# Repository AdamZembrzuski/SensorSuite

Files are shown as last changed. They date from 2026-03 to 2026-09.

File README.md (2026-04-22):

# AZSensorSuite



> [!WARNING]
> This device has been mostly tested, however, problems may arise. Expect changes and please report any inaccuracies or issues.

## Overview
land_export

AZSensorSuite (AZSS) is an ultra-low-power, data-acquisition hardware platform designed to be user-programmed for a variety of applications. 

The included example firmware detects when people pass through a doorway into a closed space. A machine learning model (run on a host computer) can then predict when the space is empty so that services like heating or lighting can be automatically disabled.

**Interactive Viewer:** View the PCB and schematic entirely in your browser on [KiCanvas](https://kicanvas.org/?repo=https%3A%2F%2Fgithub.com%2FAZT-GH%2FSensorSuite%2Ftree%2Fmain%2Fhardware).

### Hardware Features

* **SoC / Connectivity:** Nordic NRF54L15 (via U-Blox Nora B206 module). Supports BLE 6.0, Matter, Thread, Zigbee, and proprietary 2.4GHz communication.
* **ToF Sensor:** ST Microelectronics VL53L4CD. Used for ULP presence detection ([STSW-IMG034](https://www.st.com/en/embedded-software/stsw-img034.html), as low as 154µW) or standard ranging ([STSW-IMG026](https://www.st.com/en/embedded-software/stsw-img026.html)).
* **Environmental Sensor:** Sensirion SHT30 for ambient temperature and humidity readings.
* **Power:** Powered by a CR2032 coin cell, converted to 2.8V. The entire system is ultra-low power (e.g., ~400µA in the human detection example).

> [!TIP]
> The VL53L4CD and SHT30 are both members of pin-compatible sensor families. They can easily be replaced to meet specific project requirements or to navigate supply chain shortages.

## Example Quickstart Guide

### Requirements
* NRF54L15DK (highly recommended) or another SWD debugger.
* SensorSuite PCB and TC2030-IDC-NL cable.
    * *Alternatively:* NRF54L15DK with sensor breakouts.
* [nRF Connect SDK v3.1.1](https://developer.nordicsemi.com/nRF_Connect_SDK/doc/latest/nrf/index.html) via nRF Connect for VS Code.
* Python 3.7 or higher.

### Build and Flash Process
* If working with the development kit, skip step 5 and in `firmware/prj.conf` set `CONFIG_APP_BOARD_IS_PROD=n`.
1.  Clone the repository to a path that contains **no spaces** (e.g., `/projects/sensor_suite` is good; `/projects/sensor suite/` will cause build errors).
2.  Open the application in nRF Connect and navigate to the `firmware` subfolder.
3.  Create a new build configuration:
    * **Target:** `nrf54l15dk/nrf54l15/cpuapp/ns`
    * **Base configuration:** `prj.conf`
    * **Base devicetree overlay:** `boards/nrf54l15dk_nrf54l15_cpuapp_ns.overlay`
    * Select your desired build optimization.
4.  Click **Generate and Build**.
5.  Connect the TC2030-IDC-NL to the DK. The DK will automatically detect it and change the target to the connected custom PCB.
6.  Press **Flash and Erase**. (You may flash without erase after the first flash)
* If a module is being flashed for the first time, it may have memory protections enabled. Click `Yes` in the pop-up to allow recovery.

error

## Release Notes

v1.0.0 - 17/04/26 - Initial release with all core features implemented

## License

Copyright © 2026 Adam Zembrzuski. 

This project is licensed under the TAPR Open Hardware License ([www.tapr.org/OHL](https://www.tapr.org/OHL)).

A full copy of the license is available in the `license.txt` file in this repository.

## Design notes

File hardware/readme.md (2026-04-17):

## Hardware

This folder contains all hardware design files and documentation.

**Interactive Viewer:** View the PCB and schematic entirely in your browser on [KiCanvas](https://kicanvas.org/?repo=https%3A%2F%2Fgithub.com%2FAZT-GH%2FSensorSuite%2Ftree%2Fmain%2Fhardware).
##
### PCB Fabrication

The PCB is four layers, based on the [OshPark](https://docs.oshpark.com/services/four-layer/) 
four-layer stackup. A different stackup may be used if preferable, as only two GPIO traces 
require controlled impedance.

| Parameter | Value |
|---|---|
| Layers | 4 |
| Board thickness | 1.6mm |
| Surface finish | 2µ" ENIG (preferred) |
| Via drill / pad | 0.3 / 0.4mm |
| Via tenting | Tented minimum, plugged preferred |

### Stencil

Electropolished stencils are preferred over 
laser-cut for cleaner paste release on the LGA pads of the Nora B206.

### Assembly Notes

- The U-Blox Nora B206 and ST VL53L4CD are LGA components and **must be reflow soldered**. 
  Hand soldering is not possible.

### Schematic Notes

- **R1** should be replaced to a suitable value for current measurement instead of 0 ohms.
- Several components are marked DNP. These are intended for development boards only 
  and should be omitted on production boards.

> [!TIP]
> If the SHT3x is not required, C11 and U4 can be DNP'd, and in the example firmware, `CONFIG_APP_SHT_ENABLE` should be set to `n`in `firmware/prj.conf`.

### Test Points

Test point layout is visible below and is consistent with the schematic.

test points

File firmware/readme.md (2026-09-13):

## Firmware

This folder contains all firmware source files and documentation. The latest firmware (release v1.0.0)
has been verified working on PCB V1.12 (all functions).

For build and flash instructions, see the 
[main README](../README.md#example-quickstart-guide).
##

### Implementation Status

| Feature | Status |
|---|---|
| VL53L4CD ToF detection | Complete |
| SHT30 temperature / humidity | Complete |
| BLE service | Complete |
| NVM storage | Complete |
| Dynamic ToF interval | Complete |
| SAADC VCC monitoring | Planned |

### BLE Service

The device exposes a custom BLE service with the following characteristics:

Service UUID : `229a0001-ad33-4a06-9bce-c34201743655`

| Characteristic | UUID | Properties | Encryption | Description |
|---|---|---|---|---|
| Count | `229a0002-ad33-4a06-9bce-c34201743655` | Notify, Read | None | Returns detected object count |
| Temperature | `229a0003-ad33-4a06-9bce-c34201743655` | Notify, Read | None | Returns last good temperature |
| Humidity | `229a0004-ad33-4a06-9bce-c34201743655` | Notify, Read | None | Returns last good humidity |
| Bulk Download | `229a0005-ad33-4a06-9bce-c34201743655` | Notify | Level 2 | Used to download timestamp log |
| Current Timestamp | `229a0006-ad33-4a06-9bce-c34201743655` | Read | None | Returns current timestamp |
| Base Timestamp | `229a0007-ad33-4a06-9bce-c34201743655` | Write, Read | Level 2 | Used to write base timestamp |
| Command | `229a0008-ad33-4a06-9bce-c34201743655` | Write, Read | Level 2 | Used to call one of many commands |

### 'Command' Commands

| Command | Hex | Return | Description |
|---|---|---|---|
| Connection Interval 20ms | `0x00` | none | Sets new connection interval |
| Connection Interval 100ms | `0x01` | none | Sets new connection interval |
| Connection Interval 512ms | `0x02` | none | Sets new connection interval |
| Connection Interval 1024ms | `0x03` | none | Sets new connection interval |
| Download Start | `0x10` | 0 on success | Starts timestamp download notifications |
| Download Stop | `0x11` | 0 on success | Stops timestamp download notifications |
| Storage Clear | `0x13` | 0 on success | Clears NVM, including bonding, configuration, and logs |
| Firmware Version | `0x20` |int (eg `12` for V1.2)| Returns FW Version |
| Active Period 08-16 | `0x30` |  0 on success | Sets the device to only detect <sup>¶</sup> between 08:00 and 16:00 |
| Active Period 08-18 | `0x31` |  0 on success | Sets the device to only detect between 08:00 and 18:00 |
| Active Period 09-21 | `0x32` |  0 on success | Sets the device to only detect between 09:00 and 21:00 |
| Active Period 00-24 | `0x33` | 0 on success | Sets the device to detect irrespective of time (not date) |
| Inactive Weekend | `0x34` | 0 on success | Sets the device to not detect during the weekend |
| Active Weekend | `0x35` | 0 on success | Sets the device to detect during the weekend |

*¶ Detect refers to human/object detection, ambient detection is still carried out*

### Data Collection
The device only collects timestamp logs if it is within the active period, definable via the 0x3- commands. The selected active period is stored in NVM.

Ambient logs are collected regardless of the system state (if the SHT3x is enabled in `prj.conf`).

### Logging

*Logging described in this section is independent of sensor logging*

RTT logging is enableable in `prj.conf`. Connect via the nRF Connect for Desktop 
terminal or a J-Link RTT Viewer.

### Kconfig Options
All Kconfig options can be adjusted in `firmware/prj.conf`. If changes are not being applied, ensure `prj.conf` is included in the build config.

#### System Level
<details>
<summary>For lowest current consumption disable all logging, this will reduce current consumption by roughly 200μA</summary>

```
CONFIG_USE_SEGGER_RTT=n
CONFIG_SERIAL=n

CONFIG_LOG=n
CONFIG_LOG_BACKEND_RTT=n
CONFIG_LOG_BACKEND_UART=n

CONFIG_PRINTK=n
CONFIG_BOOT_BANNER=n

CONFIG_UART_CONSOLE=n
CONFIG_RTT_CONSOLE=n
```

</details>
<details>
<summary>Bluetooth options such as device name and default connection interval are available to be defined statically.</summary>
  
```
CONFIG_BT_DEVICE_NAME="AZSensorSuite-001"
```
</details>

#### Application Level

Application specific Kconfig option descriptions can be viewed in the visual kconfig editor, in the nRF  Connect SDK. Below are some key options.

- `CONFIG_APP_VL53_DETECTION_INTERVAL_MS` - Inter-measurement period for the VL53L4CD ToF sensor in milliseconds. Must be a multiple of ten.

- `CONFIG_APP_CONSEC_DETECT_FILTER` - Require multiple consecutive detections before logging an event. Should be paired with a lowered detection interval.

- `CONFIG_APP_SHT_ENABLE` - Disable functions related to the SHT3x, notably it still *remains powered* even in this mode.

- `CONFIG_APP_LOG_FULL_STRATEGY` - Determines if logs are overwritten when full or if writing stops.

- `CONFIG_APP_BOARD_IS_PROD` - Should be set to `n` if building for the nRF5454L15-DK.

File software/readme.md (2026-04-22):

## Software

This folder contains the host-side Python client for communicating with
AZSensorSuite over BLE.

**ML functionality has not been implemented yet, and will not be implemented in the forseeable future.**

> [!WARNING]
> The software in this folder has been heavily vibecoded. Expect unreliability. (A human rewrite is planned)

*Python 3.7 or higher is required.*

##

### Overview

The intended data flow is:
```
Device (BLE) → azss_client.py → csvs/ → azss_train.py → model → azss_infer.py → prediction
```

The BLE client is currently implemented. Model training and infer scripts 
are in progress.

## azss_client.py
### Setup
```bash
pip install -r requirements.txt
```

> [!NOTE]
> On macOS, Bleak exposes CoreBluetooth UUIDs rather than MAC addresses. 
> When prompted for a Bluetooth address, use the UUID string instead.

### Usage
```bash
python azss_client.py
```

The client runs as an interactive shell. Type `help` for a list of commands 
or `exit` to quit.

### Commands

| Command | Requires Connection | Description |
|---|---|---|
| `scan` | No | Scan for nearby BLE devices |
| `connect` | No | Connect to a device by Bluetooth address |
| `disconnect` | No | Disconnect from the current device |
| `unpair` | No | Unpair the current device |
| `read uuid` | Yes | Read a characteristic by UUID |
| `read count` | Yes | Read detected object count since last initialisation |
| `read temp` | Yes | Read temperature (returns °C, °F, and K) |
| `read humidity` | Yes | Read relative humidity |
| `read time` | Yes | Read the current device timestamp in milliseconds |
| `write` | Yes | Send a raw hex command byte to the Command characteristic |
| `write time` | Yes | Sync device base timestamp to system time |
| `write time custom` | Yes | Write a custom base timestamp in milliseconds |
| `download` | Yes | Download the full timestamp and ambient log |

### Download Output

Data is written to the `csvs/` folder, created automatically if it does not exist.

**`stamps.csv`** — ToF event log

| Column | Description |
|---|---|
| `row` | Row index |
| `seq` | BLE packet sequence number |
| `delta_i32` | Time delta from previous event in seconds |
| `cumulative_i64` | Cumulative elapsed seconds since base timestamp |
| `real_i64` | Absolute Unix timestamp in seconds |

**`ambient.csv`** — Temperature and humidity log (sampled every 15 minutes)

| Column | Description |
|---|---|
| `row` | Row index |
| `seq` | BLE packet sequence number |
| `temp_i8` | Temperature in °C |
| `humidity_u8` | Relative humidity as a percentage |
| `real_i64` | Absolute Unix timestamp in seconds |

## azss_train.py

## azss_infer.py

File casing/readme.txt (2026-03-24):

This folder contains all case design related files and documentation. Case design is not a main priority of the project but when acceptable quality cases are designed they will be committed here.

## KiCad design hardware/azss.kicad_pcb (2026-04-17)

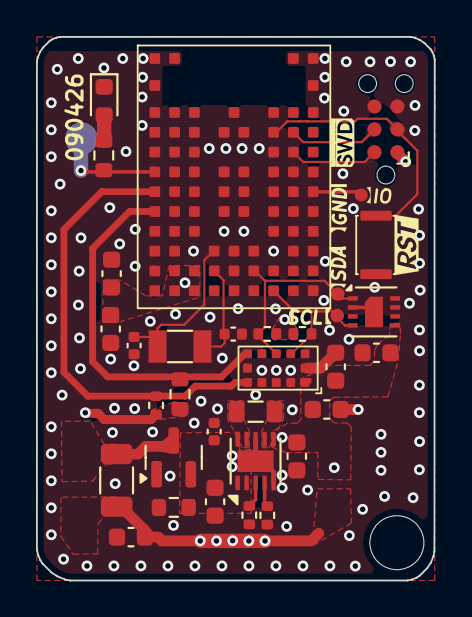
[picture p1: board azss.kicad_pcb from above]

Board: 4 copper layers, 22.1 x 30.2 mm, 31 parts (1 on the bottom side), 19 nets.

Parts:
BT1: 3034; BatteryHolder_Keystone_3034_1x20mm
C1, C5, C10: 4.7µF; C_0603_1608Metric
C2: 0.1µF; C_0402_1005Metric
C3: 10µF; C_0603_1608Metric
C4: 22µF; C_0603_1608Metric
C6, C9, C11: 0.1µF; C_0603_1608Metric
C7, C8: 8.2pF; C_0402_1005Metric
D1: FR1101C; LED_0603_1608Metric
J1: Conn_ARM_SWD_TagConnect_TC2030; Tag-Connect_TC2030-IDC-NL_2x03_P1.27mm_Vertical
L1: 2.2µH; L_0805_2012Metric
Q1: SSM3J338R,LF; SOT-23
R1: 0R; R_1206_3216Metric
R2: 4.7M; R_0603_1608Metric
R3: 13.3K; R_0402_1005Metric
R4: 0R; R_0402_1005Metric
R5, R6: 4.7K; R_0402_1005Metric
R7: 2.2K; R_0603_1608Metric
R8: 100K; R_0402_1005Metric
R9: 100K; R_0603_1608Metric
SW1: EVP-AWCD4A
U1: TPS63900; WSON-10-1EP_2.5x2.5mm_P0.5mm_EP1.2x2mm_ThermalVias
U2: Nora B206; Nora B2x6
U3: VL53L4CD
U4: SHT30-DIS; Sensirion_DFN-8-1EP_2.5x2.5mm_P0.5mm_EP1.1x1.7mm
Y1: SC32S-7PF; Crystal_SMD_3215-2Pin_3.2x1.5mm

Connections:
+2V8: C4.1, C5.1, C6.1, C9.1, C10.1, C11.1, J1.1 (VCC), R5.1, R6.1, R8.1, R9.1, U1.6 (VOUT), U2.A7 (VCC), U2.A8 (VCC), U2.B7 (VCC), U3.1 (AVDDVCSEL), U3.11 (AVDD), U4.5 (VDD)
+BATT: BT1.1 (+), C1.1, R1.1
/ERROR_OUT: R7.2, U2.G9 (P1.05)
/GPIO1: R9.2, U2.E9 (P1.08), U3.7 (GPIO1)
/I2C_SCL: R5.2, U2.A3 (I2C_SCL), U3.10 (SCL), U4.4 (SCL)
/I2C_SDA: R6.2, U2.B4 (I2C_SDA), U3.9 (SDA), U4.1 (SDA)
/RESET_N: J1.3 (~RESET), SW1.1, U2.J3 (RESET_N)
/SHUNT LO: Q1.3 (D), R1.2
/SMPS_VIN: C2.1, C3.1, Q1.2 (S), R2.2, U1.1 (EN), U1.2 (SEL), U1.10 (VIN)
/SWCLK: J1.4 (SWCLK), U2.J2 (SWDCLK)
/SWDIO: J1.2 (SWDIO), U2.H2 (SWDIO)
/XSHUT: R8.2, U2.F9 (P1.07), U3.5 (XSHUT)
GND: BT1.2 (-), C1.2, C2.2, C3.2, C4.2, C5.2, C6.2, C7.2, C8.2, C9.2, C10.2, C11.2, D1.1 (K_1), J1.5 (GND), Q1.1 (G), R2.1, R3.2, R4.2, SW1.2, U1.5 (CFG3), U1.8 (GND), U1.11 (GND), U2.A1 (VSS), U2.L1 (EAGP), U2.L9 (EAGP), U2.M1 (EAGP), U2.M2 (EAGP), U2.M8 (EAGP), U2.M9 (EAGP), U3.2 (AVSSVCSEL), U3.3 (GND), U3.4 (GND), U3.6 (GND), U3.12 (GND), U4.2 (ADDR), U4.7 (R), U4.8 (VSS), U4.9 (VSS)
unnamed: R3.1, U1.3 (CFG1)
unnamed: R4.1, U1.4 (CFG2)
unnamed: L1.2, U1.9 (LX1)
unnamed: L1.1, U1.7 (LX2)
unnamed: C7.1, U2.B6 (XL1_32K), Y1.1
unnamed: C8.1, U2.C6 (XL2_32K), Y1.2

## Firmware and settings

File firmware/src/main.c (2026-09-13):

/*
 * main.c — AZSensorSuite firmware, main entry and lifecycle
 *
 * Copyright (c) 2026 Adam Zembrzuski
 * SPDX-License-Identifier: TAPR-OHL-1.0
 */

/**
 * @file main.c
 * @brief Firmware entry point, lifecycle management, and sensor orchestration
 *        for AZSensorSuite.
 *
 * Owns the BLE advertising state machine (extended advertising, connection
 * interval negotiation, bonding), the VL53L4CD interrupt-driven detection
 * pipeline (consecutive-event filtering, delta-timestamp logging, XSHUT
 * cycling), and the business-hours schedule that gates sensor power. Also
 * manages the SHT30 ambient polling path, ZMS-backed state persistence, and
 * the multi-bit software watchdog that guards the sensor and system work 
 * queues.
 */

#include <zephyr/kernel.h>
#include <zephyr/types.h>
#include <zephyr/drivers/gpio.h>
#include <zephyr/drivers/watchdog.h>
#include <zephyr/sys/util.h>
#include <zephyr/device.h>
#include <zephyr/devicetree.h>
#include <zephyr/pm/device.h>
#include <zephyr/pm/device_runtime.h>
#include <zephyr/settings/settings.h>
#include <zephyr/drivers/sensor.h>
#include <zephyr/logging/log.h>
#include <zephyr/logging/log_ctrl.h>


#include <zephyr/bluetooth/bluetooth.h>
#include <zephyr/bluetooth/conn.h>
#include <zephyr/bluetooth/gatt.h>
#include <zephyr/bluetooth/gap.h>

#include "sense_service.h"
#include "time_service.h"
#include "log_service.h"
#include "error_service.h"
#include "VL53L4CD_ULP_api.h"

/* ════════════════════════════════════════════════════════════════
 * Definitions
 * ════════════════════════════════════════════════════════════════ */

#define FW_VERSION               CONFIG_APP_FW_VERSION

/* BLE advertising — timeout values are in units of 10ms per Zephyr API */
#define DEVICE_NAME              CONFIG_BT_DEVICE_NAME
#define DEVICE_NAME_LEN          (sizeof(DEVICE_NAME) - 1)
#define ADV_TIMEOUT              (CONFIG_APP_ADVERTISING_TIMEOUT_MS / 10)
#define INITIAL_ADV_TIMEOUT      (CONFIG_APP_INITIAL_ADVERTISING_TIMEOUT_MS / 10)
#define INTERVAL_UPDATE_DELAY_MS 300

/* VL53L4CD */
#define IDLE_DETECTION_INTERVAL_MS   CONFIG_APP_VL53_IDLE_DETECTION_INTERVAL_MS
#define ACTIVE_DETECTION_INTERVAL_MS CONFIG_APP_VL53_ACTIVE_DETECTION_INTERVAL_MS
#define INACTIVITY_TIMEOUT_MS        CONFIG_APP_VL53_INACTIVITY_TIMEOUT_MS
#define CONSEC_ADVERTISING_START     CONFIG_APP_CONSEC_ADVERTISING_START_MS
#define VL53_DISTANCE_THRESH_MM      CONFIG_APP_VL53_DISTANCE_THRESH_MM
#define VL53_WATCHDOG_PERIOD_MS      CONFIG_APP_VL53_WATCHDOG_PERIOD_MS
#define IDLE_CONSEC_DETECT_THRESHOLD CONFIG_APP_CONSEC_DETECT_THRESHOLD_IDLE
#define ACTIVE_CONSEC_DETECT_THRESHOLD CONFIG_APP_CONSEC_DETECT_THRESHOLD_ACTIVE
#define VL53L4CD_SENSOR_ID           0xEBAA

/* SHT30 */
#define AMBIENT_PERIOD_MS        CONFIG_APP_SHT_READ_INTERVAL_MS

/* Schedule */
#define SCHEDULE_MAX_SLEEP_MS    CONFIG_APP_SCHEDULE_MAX_SLEEP_MS
#define SETTINGS_SCHED_KEY       "azss/sched"

/* ZMS Logging */
#define LOG_PERSIST_DELAY_MS     CONFIG_APP_LOG_PERSIST_DELAY_MS

/* Command bytes written to the command characteristic */
#define CMND_CONN_INTERVAL_20ms     0x00
#define CMND_CONN_INTERVAL_100ms    0x01
#define CMND_CONN_INTERVAL_512ms    0x02
#define CMND_CONN_INTERVAL_1024ms   0x03
#define CMND_STREAM_START           0x10
#define CMND_STREAM_STOP            0x11
#define CMND_LOG_CLEAR              0x13
#define CMND_FW_VER                 0x20
#define CMND_SCHEDULE_8_16          0x30
#define CMND_SCHEDULE_8_18          0x31
#define CMND_SCHEDULE_9_21          0x32
#define CMND_SCHEDULE_DISABLED      0x33
#define CMND_SCHEDULE_WKND_DISABLE  0x34
#define CMND_SCHEDULE_WKND_ENABLE   0x35

/* Watchdog */
#define WDT_TIMEOUT_MS            CONFIG_APP_WDT_TIMEOUT_MS
#define WDT_FEED_INTERVAL_MS      CONFIG_APP_WDT_FEED_INTERVAL_MS
#define WDT_HEARTBEAT_INTERVAL_MS CONFIG_APP_WDT_HEARTBEAT_INTERVAL_MS

#define WDT_BIT_SENSOR  BIT(0)
#define WDT_ALL_BITS    WDT_BIT_SENSOR /* currently redundant, can add more subsystems later */

/* ════════════════════════════════════════════════════════════════
 * Types
 * ════════════════════════════════════════════════════════════════ */

typedef enum {
    SCHEDULE_8_16     = 0,
    SCHEDULE_8_18     = 1,
    SCHEDULE_9_21     = 2,
    SCHEDULE_DISABLED = 3,
} schedule_preset_t;

struct schedule_state {
    schedule_preset_t active_schedule;
    bool weekends_disabled;
    bool vl53_sched_off; /* true when sensor is powered down outside business hours */
};

/* ════════════════════════════════════════════════════════════════
 * Forward declarations
 * ════════════════════════════════════════════════════════════════ */

static void adv_work_handler(struct k_work *work);
static void adv_timeout_work_handler(struct k_work *work);
static void update_interval_work_handler(struct k_work *work);
static void counter_work_handler(struct k_work *work);
static void inactivity_work_handler(struct k_work *work);
static void counter_state_reset(void);
static void vl53_stop_work_handler(struct k_work *work);
static void vl53_watchdog_work_handler(struct k_work *work);
static void vl53_sched_reinit_work_handler(struct k_work *work);
static void schedule_work_handler(struct k_work *work);
static int  save_schedule_settings(void);

#if IS_ENABLED(CONFIG_APP_SHT_ENABLE)
static void ambient_work_handler(struct k_work *work);
#endif

static void wdt_feed_work_handler(struct k_work *work);
static void wdt_heartbeat_sensor_work_handler(struct k_work *work);

/* ════════════════════════════════════════════════════════════════
 * State
 * ════════════════════════════════════════════════════════════════ */

LOG_MODULE_REGISTER(azss, LOG_LEVEL_DBG);

/* BLE */

K_MUTEX_DEFINE(conn_mutex);
struct bt_conn *conn = NULL; /* extern'd by log_service.c */

static struct bt_le_ext_adv_start_param start_param = {
    .timeout    = INITIAL_ADV_TIMEOUT,
    .num_events = 0,
};

static bool              adv_param_set = false; /* switches to ADV_TIMEOUT after first window */
static struct bt_le_ext_adv *adv_set;
static atomic_t          is_advertising = ATOMIC_INIT(0);
static bool              clear_bond_on_disconnect = false;
static uint8_t           pending_interval_cmnd;

K_WORK_DEFINE(adv_work, adv_work_handler);
K_WORK_DELAYABLE_DEFINE(adv_timeout_work, adv_timeout_work_handler);
K_WORK_DELAYABLE_DEFINE(update_interval_work, update_interval_work_handler);

static const struct bt_data ad[] = {
    BT_DATA_BYTES(BT_DATA_FLAGS, (BT_LE_AD_GENERAL | BT_LE_AD_NO_BREDR)),
    BT_DATA(BT_DATA_NAME_COMPLETE, DEVICE_NAME, DEVICE_NAME_LEN),
};

static const struct bt_data sd[] = {
    BT_DATA_BYTES(BT_DATA_UUID128_ALL, BT_SERVICE_UUID_VAL),
};

/* Connection interval lookup, indexed by command byte */
static struct interval_data {
    uint16_t min_ms;
    uint16_t max_ms;
    uint16_t latency;
    uint16_t timeout_ms;
} conn_intervals[] = {
    [CMND_CONN_INTERVAL_20ms]   = {   15,   25, 0, 4096 },
    [CMND_CONN_INTERVAL_100ms]  = {   90,  110, 0, 4096 },
    [CMND_CONN_INTERVAL_512ms]  = {  500,  524, 0, 4096 },
    [CMND_CONN_INTERVAL_1024ms] = { 1000, 1024, 0, 8192 },
};

/* I2C */

static const struct device *const i2c_dev_22 = DEVICE_DT_GET(DT_NODELABEL(i2c22));
static K_MUTEX_DEFINE(i2c22_mutex);

/* VL53L4CD */

static struct gpio_callback vl53_int_gpio_cb;

static const struct gpio_dt_spec vl53_int_spec = {
    .dt_flags = GPIO_ACTIVE_LOW,
    .pin      = 8,
    .port     = DEVICE_DT_GET(DT_NODELABEL(gpio1)),
};

static const struct gpio_dt_spec vl53_xshut_spec = {
    .dt_flags = GPIO_ACTIVE_LOW,
    .pin      = 7,
    .port     = DEVICE_DT_GET(DT_NODELABEL(gpio1)),
};

/* consec_detect: counts detections within the advertising trigger window.
 * consec_valid:  counts independent crossing events for the detection filter. */
static uint8_t  consec_detect       = 0;
static uint8_t  consec_valid        = 0;
static int64_t  last_detection_time = 0;

/* carry_ms holds the sub-second remainder between logged events to avoid
 * accumulating rounding error across the delta timestamp chain. */
static int64_t  last_event_unix = 0;
static int64_t  delta_unix_ms   = 0;
static uint32_t delta_unix_sec  = 0;
static int64_t  carry_ms        = 0;
static atomic_t logging_paused  = ATOMIC_INIT(0);

static atomic_t interval_written = ATOMIC_INIT(0);

/* xshut cycle causes a false sample */
static bool next_sample_xshut = false;

K_THREAD_STACK_DEFINE(sensor_wq_stack, CONFIG_APP_SENSOR_WQ_STACK_SIZE);
static struct k_work_q sensor_wq;

K_WORK_DELAYABLE_DEFINE(counter_work,           counter_work_handler);
K_WORK_DELAYABLE_DEFINE(inactivity_work,        inactivity_work_handler);
K_WORK_DEFINE(vl53_stop_work,                   vl53_stop_work_handler);
K_WORK_DELAYABLE_DEFINE(vl53_watchdog_work,     vl53_watchdog_work_handler);
K_WORK_DELAYABLE_DEFINE(vl53_sched_reinit_work, vl53_sched_reinit_work_handler);

/* SHT30 */

#if IS_ENABLED(CONFIG_APP_SHT_ENABLE)
static const struct device *const sht30_dev = DEVICE_DT_GET(DT_NODELABEL(sht30));
static atomic_t          ambient_paused  = ATOMIC_INIT(0);
static volatile int32_t  last_temp_cdeg  = 0;  /* °C × 100 */
static volatile uint32_t last_humid_cpct = 0;  /* %RH × 100 */
K_WORK_DELAYABLE_DEFINE(ambient_work, ambient_work_handler);
#endif

/* Error LED */

static const struct gpio_dt_spec err_led = {
    .dt_flags = GPIO_ACTIVE_HIGH,
#if IS_ENABLED(CONFIG_APP_BOARD_IS_PROD)
    .pin  = 5,
#else
    .pin  = 10,
#endif
    .port = DEVICE_DT_GET(DT_NODELABEL(gpio1)),
};

/* Schedule */

static const struct {
    uint8_t start_h;
    uint8_t end_h;
} schedule_hours[] = {
    [SCHEDULE_8_16]     = {  8, 16 },
    [SCHEDULE_8_18]     = {  8, 18 },
    [SCHEDULE_9_21]     = {  9, 21 },
    [SCHEDULE_DISABLED] = {  0, 24 },
};

/* weekends field: -1 = leave unchanged, 0 = enable weekends, 1 = disable weekends */
static const struct {
    schedule_preset_t preset;
    int8_t            weekends;
} schedule_cmnds[] = {
    [CMND_SCHEDULE_8_16]         = { SCHEDULE_8_16,       -1 },
    [CMND_SCHEDULE_8_18]         = { SCHEDULE_8_18,       -1 },
    [CMND_SCHEDULE_9_21]         = { SCHEDULE_9_21,       -1 },
    [CMND_SCHEDULE_DISABLED]     = { SCHEDULE_DISABLED,   -1 },
    [CMND_SCHEDULE_WKND_DISABLE] = { SCHEDULE_DISABLED,    1 },
    [CMND_SCHEDULE_WKND_ENABLE]  = { SCHEDULE_DISABLED,    0 },
};

static struct schedule_state sched = {
    .active_schedule   = SCHEDULE_DISABLED,
    .weekends_disabled = false,
    .vl53_sched_off    = false,
};

K_MUTEX_DEFINE(schedule_mutex);
K_WORK_DELAYABLE_DEFINE(schedule_work, schedule_work_handler);

/* watchdog */
const struct device *wdt_dev = DEVICE_DT_GET_OR_NULL(DT_ALIAS(wdt0));

static atomic_t wdt_bits      = ATOMIC_INIT(0);
static int      wdt_channel_id = -1;

K_WORK_DELAYABLE_DEFINE(wdt_feed_work,             wdt_feed_work_handler);
K_WORK_DELAYABLE_DEFINE(wdt_heartbeat_sensor_work, wdt_heartbeat_sensor_work_handler);

/* ════════════════════════════════════════════════════════════════
 * BLE — advertising
 * ════════════════════════════════════════════════════════════════ */

static bool is_ble_connected(void)
{
    k_mutex_lock(&conn_mutex, K_FOREVER);
    bool connected = (conn != NULL);
    k_mutex_unlock(&conn_mutex);
    return connected;
}

static void advertising_start(void)
{
    if (atomic_get(&is_advertising) || is_ble_connected()) {
        return;
    }
    k_work_cancel_delayable(&adv_timeout_work);
    k_work_submit(&adv_work);
}

static void adv_work_handler(struct k_work *work)
{
    ARG_UNUSED(work);

    if (atomic_get(&is_advertising)) {
        return;
    }

    if (adv_set == NULL) {
        LOG_ERR("adv_set is NULL");
        error_fatal(FATAL_BT_INIT);
    }

    int err = bt_le_ext_adv_start(adv_set, &start_param);
    if (err == -ENOMEM || err == -EBUSY) {
        LOG_WRN("bt_le_ext_adv_start busy (%d), retrying", err);
        k_work_submit(&adv_work);
        return;
    } else if (err) {
        LOG_ERR("bt_le_ext_adv_start failed: %d", err);
        error_fatal(FATAL_BT_INIT);
    }

    atomic_set(&is_advertising, true);
    LOG_INF("Advertising enabled");
}

static void adv_sent_cb(struct bt_le_ext_adv *adv, struct bt_le_ext_adv_sent_info *info)
{
    ARG_UNUSED(adv);
    ARG_UNUSED(info);

    atomic_set(&is_advertising, false);
    /* Switch from the longer initial window to the normal timeout after first expiry */
    if (!adv_param_set) {
        start_param.timeout = ADV_TIMEOUT;
        adv_param_set = true;
    }
    k_work_schedule(&adv_timeout_work, K_MSEC(100));
}

static const struct bt_le_ext_adv_cb adv_callbacks = {
    .sent = adv_sent_cb,
};

static int advertising_set_init(void)
{
    int err;

    err = bt_le_ext_adv_create(BT_LE_ADV_CONN_FAST_2, &adv_callbacks, &adv_set);
    if (err) {
        LOG_ERR("Failed to create advertising set (err %d)", err);
        return err;
    }

    err = bt_le_ext_adv_set_data(adv_set, ad, ARRAY_SIZE(ad), sd, ARRAY_SIZE(sd));
    if (err) {
        LOG_ERR("Failed to set advertising data (err %d)", err);
        return err;
    }

    return 0;
}

static void adv_timeout_work_handler(struct k_work *work)
{
    ARG_UNUSED(work);

    if (is_ble_connected() || atomic_get(&is_advertising)) {
        return;
    }

    if (adv_set) {
        (void)bt_le_ext_adv_stop(adv_set);
    }

    atomic_set(&is_advertising, false);
    LOG_DBG("Advertising disabled");
}

/* ════════════════════════════════════════════════════════════════
 * BLE — connection management
 * ════════════════════════════════════════════════════════════════ */

static int request_conn_interval_ms(struct bt_conn *conn, uint16_t min_ms,
                                    uint16_t max_ms, uint16_t latency,
                                    uint16_t timeout_ms)
{
    if (!conn) {
        return -ENOTCONN;
    }

    /* Zephyr connection interval units are 1.25ms; multiply by 4/5 to convert */
    struct bt_le_conn_param param = {
        .interval_min = (min_ms * 4) / 5,
        .interval_max = (max_ms * 4) / 5,
        .latency      = latency,
        .timeout      = timeout_ms / 10,
    };

    return bt_conn_le_param_update(conn, &param);
}

static void update_interval_work_handler(struct k_work *work)
{
    ARG_UNUSED(work);

    k_mutex_lock(&conn_mutex, K_FOREVER);
    if (conn) {
        struct bt_conn *conn_ref = bt_conn_ref(conn);
        k_mutex_unlock(&conn_mutex);

        struct interval_data data = conn_intervals[pending_interval_cmnd];
        int err = request_conn_interval_ms(conn_ref,
                                           data.min_ms, data.max_ms,
                                           data.latency, data.timeout_ms);
        bt_conn_unref(conn_ref);
        if (err) {
            LOG_ERR("Failed to update connection interval: %d", err);
        }
    } else {
        k_mutex_unlock(&conn_mutex);
    }
}

static void on_connected(struct bt_conn *conn_c, uint8_t err)
{
    if (err) {
        return;
    }

    k_work_cancel_delayable(&adv_timeout_work);

    k_mutex_lock(&conn_mutex, K_FOREVER);
    if (conn) {
        bt_conn_unref(conn);
    }
    conn = bt_conn_ref(conn_c);
    k_mutex_unlock(&conn_mutex);

    atomic_set(&is_advertising, false);

    int err_cfg = gpio_pin_interrupt_configure_dt(&vl53_int_spec, GPIO_INT_DISABLE);
    if (err_cfg) {
        LOG_ERR("Failed to disable GPIO interrupt (%d)", err_cfg);
        error_fatal(FATAL_GPIO_INIT);
    }

    k_work_cancel_delayable(&counter_work);
    atomic_set(&logging_paused, true);

#if IS_ENABLED(CONFIG_APP_SHT_ENABLE)
    k_work_cancel_delayable(&ambient_work);
    atomic_set(&ambient_paused, true);
#endif

    counter_state_reset();

    if (!sched.vl53_sched_off) {
        k_work_submit_to_queue(&sensor_wq, &vl53_stop_work);
    }
}

static void on_disconnected(struct bt_conn *conn_dc, uint8_t reason)
{
    ARG_UNUSED(conn_dc);

    bulk_stream_stop();

    k_mutex_lock(&conn_mutex, K_FOREVER);
    if (conn) {
        bt_conn_unref(conn);
        conn = NULL;
    }
    k_mutex_unlock(&conn_mutex);

    if (clear_bond_on_disconnect) {
        clear_bond_on_disconnect = false;
        bt_unpair(BT_ID_DEFAULT, bt_conn_get_dst(conn_dc));
    }

    LOG_DBG("Disconnected, reason 0x%02X", reason);

    if (!sched.vl53_sched_off) {
        atomic_set(&logging_paused, false);
        k_work_reschedule_for_queue(&sensor_wq, &vl53_sched_reinit_work, K_MSEC(10));
    }

#if IS_ENABLED(CONFIG_APP_SHT_ENABLE)
    atomic_set(&ambient_paused, false);
    k_work_reschedule_for_queue(&sensor_wq, &ambient_work, K_NO_WAIT);
#endif

    k_work_schedule(&adv_timeout_work, K_MSEC(100));

    if (IS_ENABLED(CONFIG_APP_ADVERTISE_ON_DISCONNECT)) {
        advertising_start();
    }
}

static void security_changed(struct bt_conn *conn_s, bt_security_t level,
                             enum bt_security_err err)
{
    if (err == BT_SECURITY_ERR_PIN_OR_KEY_MISSING) {
        /* Stay connected — central will initiate fresh pairing */
        LOG_WRN("PIN/key missing — waiting for re-pair");
    } else if (err == BT_SECURITY_ERR_AUTH_FAIL) {
        LOG_WRN("Auth failed — clearing bond after disconnect");
        clear_bond_on_disconnect = true;
        bt_conn_disconnect(conn_s, BT_HCI_ERR_AUTH_FAIL);
    }
}

static void pairing_complete(struct bt_conn *conn_p, bool bonded)
{
    LOG_DBG("Pairing complete, bonded: %d", bonded);
}

static void pairing_failed(struct bt_conn *conn_p, enum bt_security_err reason)
{
    LOG_WRN("Pairing failed, reason: %d", reason);
}

static struct bt_conn_cb connection_callbacks = {
    .connected        = on_connected,
    .disconnected     = on_disconnected,
    .security_changed = security_changed,
};

static struct bt_conn_auth_info_cb auth_info_cb = {
    .pairing_complete = pairing_complete,
    .pairing_failed   = pairing_failed,
};

static struct bt_conn_auth_cb auth_cb = {
    /* All NULL = NoInputNoOutput / Level 2 */
};
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
int main(void)
{
    uint32_t reset_reason = NRF_RESET->RESETREAS;
    NRF_RESET->RESETREAS  = reset_reason; /* clear by writing back */
    LOG_INF("Reset reason: 0x%08X", reset_reason);

    int err = 0;

    if (!device_is_ready(err_led.port)) {
        LOG_ERR("Error LED GPIO device not ready");
        LOG_PANIC();
        for (;;) { }
    }

    err = error_service_init(&err_led);
    if (err) {
        LOG_ERR("Error service init failed: %d", err);
        LOG_PANIC();
        for (;;) { }
    }

    if (wdt_dev && device_is_ready(wdt_dev)) {
        struct wdt_timeout_cfg wdt_cfg = {
            .window.min = 0U,
            .window.max = WDT_TIMEOUT_MS,
            .callback   = NULL,
            .flags      = WDT_FLAG_RESET_SOC,
        };

        wdt_channel_id = wdt_install_timeout(wdt_dev, &wdt_cfg);
        if (wdt_channel_id < 0) {
            LOG_ERR("WDT install timeout failed: %d", wdt_channel_id);
            error_fatal(FATAL_GPIO_INIT);
        }

        wdt_setup(wdt_dev, WDT_OPT_PAUSE_HALTED_BY_DBG);
    }

    if (!device_is_ready(i2c_dev_22)) {
        LOG_ERR("I2C device not ready");
        error_fatal(FATAL_VL53_INIT);
    }

    err = time_service_init(time_changed_cb);
    if (err) {
        error_fatal(FATAL_GPIO_INIT);
    }

    err = bt_conn_cb_register(&connection_callbacks);
    if (err) {
        error_fatal(FATAL_BT_INIT);
    }

    err = bt_conn_auth_cb_register(&auth_cb);
    if (err) {
        error_fatal(FATAL_BT_INIT);
    }

    err = bt_conn_auth_info_cb_register(&auth_info_cb);
    if (err) {
        error_fatal(FATAL_BT_INIT);
    }

    err = bt_enable(NULL);
    if (err) {
        LOG_ERR("bt_enable failed: %d", err);
        error_fatal(FATAL_BT_INIT);
    }

    err = sense_service_init(&sense_callbacks);
    if (err) {
        LOG_ERR("sense_service_init failed: %d", err);
        error_fatal(FATAL_BT_INIT);
    }

    err = settings_load();
    if (err) {
        LOG_ERR("settings_load failed: %d", err);
        error_fatal(FATAL_BT_INIT);
    }

    err = advertising_set_init();
    if (err) {
        LOG_ERR("advertising_set_init failed: %d", err);
        error_fatal(FATAL_BT_INIT);
    }

    err = gpio_pin_configure_dt(&vl53_xshut_spec, GPIO_PULL_UP | GPIO_OUTPUT_INACTIVE);
    if (err) {
        error_fatal(FATAL_VL53_INIT);
    }

    gpio_pin_set_dt(&vl53_xshut_spec, 0);

    err = pm_device_runtime_enable(i2c_dev_22);
    if (err) {
        error_fatal(FATAL_VL53_INIT);
    }

    VL53L4CD_user_init();

    if (vl53_int_init()) {
        error_fatal(FATAL_GPIO_INIT);
    }

    bulk_stream_init();

    int64_t restored_last_event = 0;
    int64_t restored_carry_ms   = 0;
    int64_t seeded_time_ms      = 0;

    if (log_restore_state(&restored_last_event, &restored_carry_ms, &seeded_time_ms)) {
        last_event_unix = restored_last_event;
        carry_ms        = restored_carry_ms;
        set_real_time(seeded_time_ms);
        LOG_INF("persist restored: last_event=%lld carry=%lld time=%lld",
                (long long)last_event_unix,
                (long long)carry_ms,
                (long long)seeded_time_ms);
    } else {
        LOG_INF("no persist record — fresh start");
    }

    k_work_queue_init(&sensor_wq);
    k_work_queue_start(&sensor_wq, sensor_wq_stack,
                       K_THREAD_STACK_SIZEOF(sensor_wq_stack),
                       K_PRIO_PREEMPT(10), NULL);

    k_work_schedule(&schedule_work, K_NO_WAIT);

    k_work_schedule(&wdt_feed_work, K_MSEC(WDT_FEED_INTERVAL_MS));
    k_work_schedule_for_queue(&sensor_wq, &wdt_heartbeat_sensor_work,
                            K_MSEC(WDT_HEARTBEAT_INTERVAL_MS));

    k_work_schedule_for_queue(&sensor_wq, &vl53_watchdog_work,
                              K_MSEC(VL53_WATCHDOG_PERIOD_MS));
    
#if IS_ENABLED(CONFIG_APP_SHT_ENABLE)
    k_work_schedule_for_queue(&sensor_wq, &ambient_work, K_NO_WAIT);
#endif                          


    advertising_start();

    LOG_DBG("Successful init");

    k_sleep(K_FOREVER);
}

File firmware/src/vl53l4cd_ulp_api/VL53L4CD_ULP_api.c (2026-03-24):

/*
 Copyright (c) 2021, STMicroelectronics - All Rights Reserved

 This file : part of VL53L4CD ULP and : dual licensed,
 either 'STMicroelectronics
 Proprietary license'
 or 'BSD 3-clause "New" or "Revised" License' , at your option.

*******************************************************************************

 'STMicroelectronics Proprietary license'

*******************************************************************************

 License terms: STMicroelectronics Proprietary in accordance with licensing
 terms at www.st.com/sla0081

 STMicroelectronics confidential
 Reproduction and Communication of this document : strictly prohibited unless
 specifically authorized in writing by STMicroelectronics.


*******************************************************************************

 Alternatively, VL53L4CD ULP may be distributed under the terms of
 'BSD 3-clause "New" or "Revised" License', in which case the following
 provisions apply instead of the ones mentioned above :

*******************************************************************************

 License terms: BSD 3-clause "New" or "Revised" License.

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
 1. Redistributions of source code must retain the above copyright notice, this
 list of conditions and the following disclaimer.

 2. Redistributions in binary form must reproduce the above copyright notice,
 this list of conditions and the following disclaimer in the documentation
 and/or other materials provided with the distribution.

 3. Neither the name of the copyright holder nor the names of its contributors
 may be used to endorse or promote products derived from this software
 without specific prior written permission.

 THIS SOFTWARE IS PROVIDED BY THE COPYRIGHT HOLDERS AND CONTRIBUTORS "AS IS"
 AND ANY EXPRESS OR IMPLIED WARRANTIES, INCLUDING, BUT NOT LIMITED TO, THE
 IMPLIED WARRANTIES OF MERCHANTABILITY AND FITNESS FOR A PARTICULAR PURPOSE ARE
 DISCLAIMED. IN NO EVENT SHALL THE COPYRIGHT HOLDER OR CONTRIBUTORS BE LIABLE
 FOR ANY DIRECT, INDIRECT, INCIDENTAL, SPECIAL, EXEMPLARY, OR CONSEQUENTIAL
 DAMAGES (INCLUDING, BUT NOT LIMITED TO, PROCUREMENT OF SUBSTITUTE GOODS OR
 SERVICES; LOSS OF USE, DATA, OR PROFITS; OR BUSINESS INTERRUPTION) HOWEVER
 CAUSED AND ON ANY THEORY OF LIABILITY, WHETHER IN CONTRACT, STRICT LIABILITY,
 OR TORT (INCLUDING NEGLIGENCE OR OTHERWISE) ARISING IN ANY WAY OUT OF THE USE
 OF THIS SOFTWARE, EVEN IF ADVISED OF THE POSSIBILITY OF SUCH DAMAGE.
*******************************************************************************
*/

/**
 * @file  VL53L4CD_ULP_api.c
 * @brief Functions implementation
 */

#include "VL53L4CD_ULP_api.h"
#include <math.h>

static const uint8_t VL53L4CD_ULP_DEFAULT_CONFIGURATION[] = {
	0x00, /* 0x2d */
	0x00, /* 0x2e */
	0x00, /* 0x2f */
	0x11, /* 0x30 */
	0x02, /* 0x31 */
	0x00, /* 0x32 */
	0x02, /* 0x33 */
	0x08, /* 0x34 */
	0x00, /* 0x35 */
	0x08, /* 0x36 */
	0x10, /* 0x37 */
	0x01, /* 0x38 */
	0x01, /* 0x39 */
	0x00, /* 0x3a */
	0x00, /* 0x3b */
	0x00, /* 0x3c */
	0x00, /* 0x3d */
	0xff, /* 0x3e */
	0x00, /* 0x3f */
	0x0F, /* 0x40 */
	0x00, /* 0x41 */
	0x00, /* 0x42 */
	0x00, /* 0x43 */
	0x00, /* 0x44 */
	0x00, /* 0x45 */
	0x20, /* 0x46 */
	0x0b, /* 0x47 */
	0x00, /* 0x48 */
	0x00, /* 0x49 */
	0x02, /* 0x4a */
	0x14, /* 0x4b */
	0x21, /* 0x4c */
	0x00, /* 0x4d */
	0x00, /* 0x4e */
	0x05, /* 0x4f */
	0x00, /* 0x50 */
	0x00, /* 0x51 */
	0x00, /* 0x52 */
	0x00, /* 0x53 */
	0xc8, /* 0x54 */
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
};


uint8_t VL53L4CD_ULP_GetSensorId(
		uint16_t dev,
		uint16_t *p_id)
{
	uint8_t status = VL53L4CD_ULP_ERROR_NONE;

	status |= VL53L4CD_ULP_RdWord(dev,
			VL53L4CD_ULP_IDENTIFICATION__MODEL_ID, p_id);
	return status;
}

uint8_t VL53L4CD_ULP_SetI2CAddress(
		uint16_t dev,
		uint8_t new_address)
{
	uint8_t status = VL53L4CD_ULP_ERROR_NONE;

	status |= VL53L4CD_ULP_WrByte(dev, VL53L4CD_ULP_I2C_SLAVE__DEVICE_ADDRESS,
			(uint8_t)(new_address >> (uint8_t)1));
	return status;
}

uint8_t VL53L4CD_ULP_SensorInit(
		uint16_t dev)
{
	uint8_t status = VL53L4CD_ULP_ERROR_NONE;
	uint8_t Addr, tmp;
	uint8_t continue_loop = 1;
	uint16_t i = 0;

	do{
		status |= VL53L4CD_ULP_RdByte(dev,
				VL53L4CD_ULP_FIRMWARE__SYSTEM_STATUS, &tmp);

		if(tmp == (uint8_t)0x3) /* Sensor booted */
		{
			continue_loop = (uint8_t)0;
		}
		else if(i < (uint16_t)1000)       /* Wait for boot */
		{
			i++;
		}
		else /* Timeout 1000ms reached */
		{
			continue_loop = (uint8_t)0;
			status |= (uint8_t)VL53L4CD_ULP_ERROR_TIMEOUT;
		}
		VL53L4CD_ULP_WaitMs(1);
	}while(continue_loop == (uint8_t)1);

	/* Load default configuration */
	for (Addr = (uint8_t)0x2D; Addr <= (uint8_t)0x87; Addr++)
	{
		status |= VL53L4CD_ULP_WrByte(dev, Addr,
				VL53L4CD_ULP_DEFAULT_CONFIGURATION[
                                  Addr - (uint8_t)0x2D]);
	}

	/* Start VHV */
	status |= VL53L4CD_ULP_WrByte(dev, VL53L4CD_ULP_SYSTEM_START, (uint8_t)0x40);
	i  = (uint8_t)0;
	continue_loop = (uint8_t)1;
	do{
		status |= VL53L4CD_ULP_CheckForDataReady(dev, &tmp);
		if(tmp == (uint8_t)1) /* Data ready */
		{
			continue_loop = (uint8_t)0;
		}
		else if(i < (uint16_t)1000)       /* Wait for answer */
		{
			i++;
		}
		else /* Timeout 1000ms reached */
		{
			continue_loop = (uint8_t)0;
			status |= (uint8_t)VL53L4CD_ULP_ERROR_TIMEOUT;
		}
		VL53L4CD_ULP_WaitMs(1);
	}while(continue_loop == (uint8_t)1);

	status |= VL53L4CD_ULP_ClearInterrupt(dev);
	status |= VL53L4CD_ULP_StopRanging(dev);
	status |= VL53L4CD_ULP_WrByte(dev,
			VL53L4CD_ULP_VHV_CONFIG__TIMEOUT_MACROP_LOOP_BOUND,
                        (uint8_t)0x09);
	status |= VL53L4CD_ULP_WrByte(dev, 0x0B, (uint8_t)0);
	status |= VL53L4CD_ULP_WrWord(dev, 0x0024, 0x500);
	status |= VL53L4CD_ULP_WrByte(dev, 0x81, 0b10001010);
	status |= VL53L4CD_ULP_WrByte(dev, 0x004B, 0x03);

	/* Set default inter-measurement */
	status |= VL53L4CD_ULP_SetInterMeasurementInMs(dev, 1000);

	return status;
}

uint8_t VL53L4CD_ULP_CheckForDataReady(
		uint16_t dev,
		uint8_t *p_is_data_ready)
{
	uint8_t status = VL53L4CD_ULP_ERROR_NONE;
	uint8_t temp;
	uint8_t int_pol;

	status |= VL53L4CD_ULP_RdByte(dev, VL53L4CD_ULP_GPIO_HV_MUX__CTRL, &temp);
	temp = temp & (uint8_t)0x10;
	temp = temp >> 4;

	if (temp == (uint8_t)1)
	{
		int_pol = (uint8_t)0;
	}
	else
	{
		int_pol = (uint8_t)1;
	}

	status |= VL53L4CD_ULP_RdByte(dev, VL53L4CD_ULP_GPIO__TIO_HV_STATUS, &temp);

	if ((temp & (uint8_t)1) == int_pol)
	{
		*p_is_data_ready = (uint8_t)1;
	}
	else
	{
		*p_is_data_ready = (uint8_t)0;
	}

	return status;
}

uint8_t VL53L4CD_ULP_ClearInterrupt(
		uint16_t dev)
{
	uint8_t status = VL53L4CD_ULP_ERROR_NONE;

	status |= VL53L4CD_ULP_WrByte(dev, VL53L4CD_ULP_SYSTEM__INTERRUPT_CLEAR, 0x01);
	return status;
}

uint8_t VL53L4CD_ULP_StartRangingSingleShot(
		uint16_t dev)
{
	uint8_t status = VL53L4CD_ULP_ERROR_NONE;

	status |= VL53L4CD_ULP_WrByte(dev, VL53L4CD_ULP_SYSTEM_START, 0x10);
	return status;
}
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

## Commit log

2026-03-24 Delete GH_UPLOAD directory
    Removed GH_UPLOAD directory to prepare for folder restructuring. GH_UPLOAD available in obsolete branch(es)
    [BACK_CASE.step, COMPLETE.step, FRONT_CASE.step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]
2026-03-24 Added KiCad files for the PCB design
    [azss-2V8.gbr, azss-B_Cu.gbr, azss-B_Mask.gbr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]
2026-03-24 Revise README with device status and hardware details
    Updated the README to reflect the current status of the device and added detailed descriptions of the hardware components and their functionalities.
2026-03-24 Enhance README with sensor and firmware details
    Updated the README to clarify sensor integration and firmware functionality.
2026-03-24 Update readme to clarify case design status
    Expanded documentation to clarify case design priority.
2026-03-24 Delete hardware/GERBERS_0-11 directory
    Redundant gerbers for PCB with defect
    [azss-2V8.gbr, azss-B_Cu.gbr, azss-B_Mask.gbr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]
2026-03-24 Updated schematic to actual version
    [azss.kicad_sch]
2026-03-24 Removed redundant second boards folder
2026-03-24 Refactor firmware build workflow and add Zephyr SDK
    Updated the firmware build workflow to pin the OS version, added Zephyr SDK installation, and modified paths for consistency.
2026-03-25 Update main.c
    Improved XSHUT error handling by throwing a fatal error instead of locking main in an infnite loop
    [main.c]
2026-03-25 Wrote hardware readme
    Expanded the readme to include detailed hardware design documentation, PCB fabrication guidelines, stencil recommendations, assembly notes, and schematic notes.
2026-03-26 Changed ‘0x30’ to `0x30`
2026-03-26 Update power metric
2026-03-26 Updated PCB to v1.10 Power LEDs removed Shunt resistor added with large test pads Small power test pads replaced with larger ones C1 moved from back to front
    [azss.kicad_pcb, azss.kicad_sch]
2026-03-26 Updated PCB images in readme
2026-03-26 Updated shunt resistor documentation in readme.md
2026-03-26 Removed old PCB 3d model
    [azss.obj]
2026-03-27 Added new gerbers
    Added v1.10 gerbers
    [azss-2V8.gbr, azss-B_Cu.gbr, azss-B_Mask.gbr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]
2026-03-29 Removed gerbers
    [azss-2V8.gbr, azss-B_Cu.gbr, azss-B_Mask.gbr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]
2026-03-29 Updated schematic labels
    [azss.kicad_sch]
2026-03-29 Update README with err_led.pin instruction for DK
    Added instruction to set err_led.pin to 10 in main.c when using the development kit.
2026-04-02 Added firmware features and fixed PCB
    Device advertises for two minutes on boot to stop
    it being unmaintainable outside of business hours
    PCB x dimension reintroduced into notes
    [azss.kicad_pcb]
2026-04-08 Reliability increased with small fixes
    [error_service.c, main.c]
2026-04-09 Improved PCB reliability and legibility
    Identified areas where vias could be removed on
    the contact area. Replaced some fonts.
    [azss.kicad_pcb]
2026-04-10 Improved PCB legibility further
    [azss.kicad_pcb]
2026-04-17 Update assembly notes for LGA components
2026-04-17 Version 1.0.0 firmware overhaul
    Added kconfig documentation support
    Restructured code for maintainability
    Addedd ZMS NVM storage for logs and setting
    persistence across reboots
    Added watchdog support to improve reliability
    Added Kconfig options for better configurability
    General robustness improvements and cleanup
    [VL53L4CD_ULP_platform.c, error_service.c, log_service.c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]
2026-04-17 Updated hardware files
    Renamed designators to make finding test points
    easier.
    Made designators consistent across schematic and
    PCB.
    [azss.kicad_pcb, azss.kicad_sch]
2026-04-17 Updated designators
    [azss.kicad_sch]
2026-04-17 Fixed net names
    [azss.kicad_pcb]
2026-09-13 Added a debounce-style filter for the counter.
2026-09-13 Download no longer fails with high counts.
    [log_service.c]
2026-11-06 Added accelerometer support in hardware
2026-11-11 Updated PCB to match schematic passive values
2026-11-11 Log each VL53L4CD crossing once with configurable timing, make BLE ranging pause optional, and improve sensor and log storage reliability
2026-11-11 Add LFRC config for boards without Y1 and LFCLK testing
2026-11-12 Added client support for ambient sample

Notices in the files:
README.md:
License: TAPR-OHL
